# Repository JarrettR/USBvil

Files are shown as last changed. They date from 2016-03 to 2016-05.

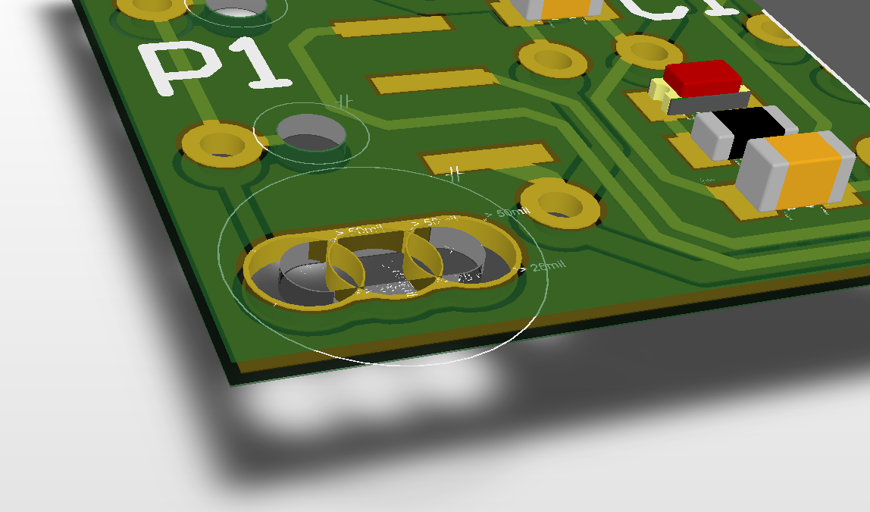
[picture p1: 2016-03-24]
Images/slots.PNG

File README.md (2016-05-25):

# USBvil
Don't plug in unknown flashdrives!

# What is this?

A demonstration of why flashdrives of unknown pedigree can be very dangerous.

See:
http://jrainimo.com/build/?p=601

The original goal was to have a very inexpensive (<$5) dev board that can be left in projects without feeling guilty. But it quickly turned into a USB experimentation project.

It fits into a standard USB flashdrive case, because that's super convenient, and it has one 8-pin port broken out for whatever this gets used for.

The "Blink.X" project in the firmware folder does exactly what it says on the tin. It's the obvious starter firmware to be forked for other stuff.

# Why is it dangerous?

The other two projects, HID and HID2 are slightly more complicated.
HID identifies itself as a USB keyboard and immediately starts typing a-z, and 0-9 upon being plugged in. This is barely changed from the Microchip example code, and doesn't include their USB libraries.

HID2 uses the same libraries, and identifies itself as a HID keyboard as well. It types `GUI-key->R, notepad.exe, hello world`. On a Windows machine, this opens Notepad and types "hello world".

Innocuous, but it's pretty obvious that this can be used in pretty scary ways.

That's pretty much as far as I intend to take this, I've lost interest. There might be methods of detecting what kind of computer the drive gets plugged into and tailoring the attack, too.

# How do I get started?

If you don't have the latest version of Microchip [MPLAB X](http://www.microchip.com/mplab/mplab-x-ide) and the [XC8 compiler](http://www.microchip.com/mplab/compilers), download them at the links. Everything is free.

To compile this, you'll need to go [here](http://www.microchip.com/mplab/microchip-libraries-for-applications) and download Microchip Libraries for Applications. It also includes some other very cool USB stuff.

After installation, go to whereever you installed it, and copy the `mla` folder into `Firmware` in this repo.

At the very least, you should have `USBvil\Firmware\mla\bsp` and `USBvil\Firmware\mla\framework` and all of the files inside.

After that, open up MPLAB, open project, and navigate to the `HID` folder - This is the more vanilla version, and better for starting something new. Compile it once to test, and then start modifying! `main.c` and `app_device_keyboard.c` are where the fun happens.

Alternatively, I have included the hex and elf firmware images if you just want to flash the board.

# How do I make one?

Just for kicks, I'm testing out Kitnic. Check it [here](https://kitnic.it/boards/github.com/JarrettR/USBvil/).

The service should make the board/BOM ordering process a little bit easier, we'll see how it goes. That's just a landing page to this repo, so all of the data is here, too.

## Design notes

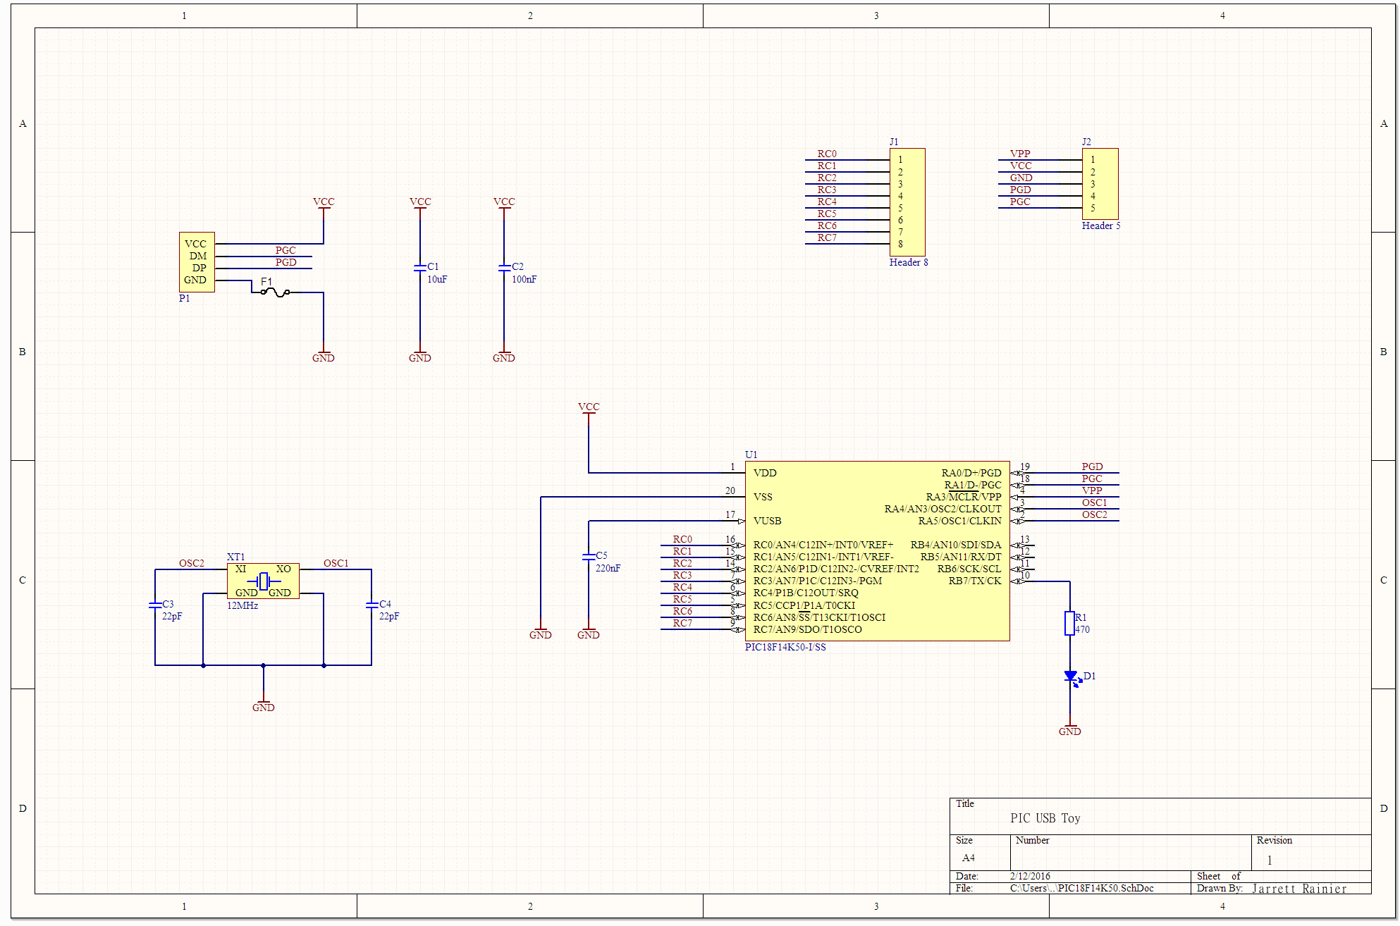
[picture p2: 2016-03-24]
Images/Schematic 1.PNG

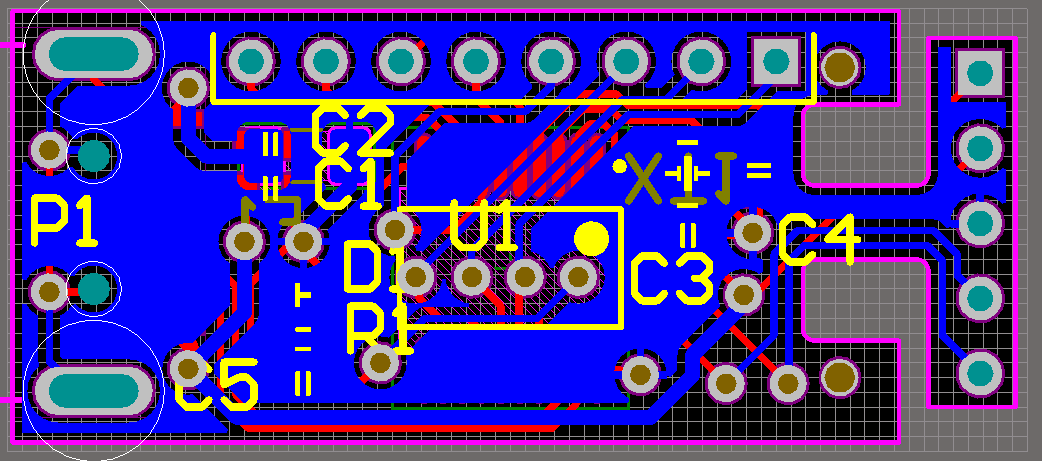
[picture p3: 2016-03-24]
Images/PCB Bottom.PNG

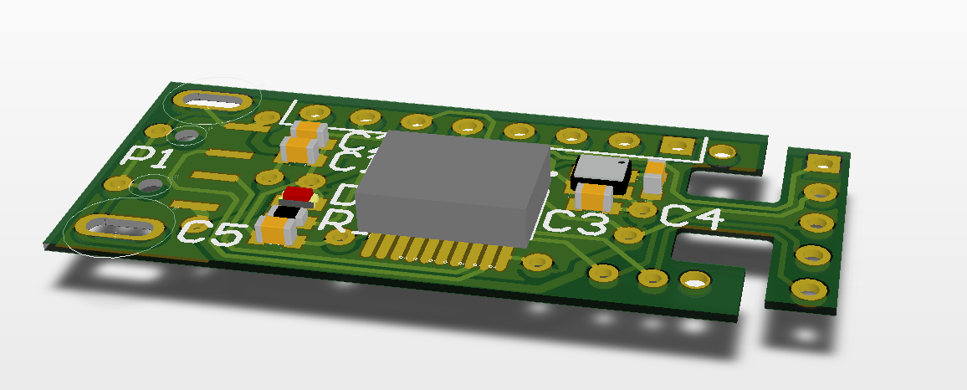
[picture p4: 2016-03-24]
Images/3D.PNG

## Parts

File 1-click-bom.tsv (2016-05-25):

References | Qty | Description | Manufacturer | MPN | Digikey | Mouser | RS | Newark | Farnell
C1 | 1 | MLCC - SMD/SMT 0603 1.0uF 6.3volts | Murata Electronics | GRM033R60J105MEA2D | 490-7229-1-ND | 81-GRM033R60J105ME2D
C2 | 1 | MLCC - SMD/SMT 0603 0.1uF 6.3volts | Murata Electronics | GRM033R60J104KE19D | 490-3167-1-ND | 81-GRM033R60J104KE19
C3, C4 | 2 | MLCC - SMD/SMT 0603 22pF 50volts | Murata Electronics | GRM0335C1H200GA01D | 490-6122-1-ND | 81-GRM0335C1H200GA1D
C5 | 1 | MLCC - SMD/SMT 0603 0.22uF 6.3volts | Murata Electronics | GRM033R60J224ME15D | 490-10407-1-ND | 81-GRM033R60J224ME5D
P1 | 1 | USB Connectors USB A PLUG SMT | Molex | 48037-2200 | WM3983CT-ND | 538-48037-2200
F1 | 1 | PTC RESTTBLE 0.75A 6V CHIP 1206 | Bel Fuse | 0ZCJ0075FF2E | 507-1804-1-ND | 530-0ZCJ0075FF2E
J1 | 1 | Female header, 8 position, unpopulated
J2 | 1 | Female header, 5 position, unpopulated
XT1 | 1 | 12MHz Crystal 20pF Surface Mount 4-SMD, No Lead (DFN, LCC) | CTS-Frequency Controls | 403C35E12M00000 | CTX1218CT-ND | 774-403C35E12M00000
U1 | 1 | IC MCU 8BIT 16KB FLASH 20SSOP | Microchip | PIC18F14K50-I/SS | PIC18F14K50-I/SS-ND | 579-PIC18F14K50-I/SS
R1 | 1 | RES SMD 470 OHM 5% 1/10W 0603 | Yageo | RC0603JR-07470RL | 311-470GRCT-ND | 603-RC0603JR-07470RL
D1 | 1 | LED BLUE CLEAR 0603 SMD | Wurth Electronics | 150060BS75000 | 732-4966-1-ND | 710-150060BS75000

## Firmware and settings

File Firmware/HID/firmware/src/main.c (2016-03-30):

/*******************************************************************************
  Main Demo File

  Company:
    Microchip Technology Inc.

  File Name:
    main.c

  Summary:
    Main demo file for keyboard project.  Entry point for compiler.

  Description:
    Main demo file for keyboard project.  Entry point for compiler.  Also
    calls the system initailization and handles system issues like calling the
    demo code appropriately and handing device level events from the USB stack.
*******************************************************************************/

// DOM-IGNORE-BEGIN
/*******************************************************************************
Copyright (c) 2013 released Microchip Technology Inc.  All rights reserved.

Microchip licenses to you the right to use, modify, copy and distribute
Software only when embedded on a Microchip microcontroller or digital signal
controller that is integrated into your product or third party product
(pursuant to the sublicense terms in the accompanying license agreement).

You should refer to the license agreement accompanying this Software for
additional information regarding your rights and obligations.

SOFTWARE AND DOCUMENTATION ARE PROVIDED "AS IS" WITHOUT WARRANTY OF ANY KIND,
EITHER EXPRESS OR IMPLIED, INCLUDING WITHOUT LIMITATION, ANY WARRANTY OF
MERCHANTABILITY, TITLE, NON-INFRINGEMENT AND FITNESS FOR A PARTICULAR PURPOSE.
IN NO EVENT SHALL MICROCHIP OR ITS LICENSORS BE LIABLE OR OBLIGATED UNDER
CONTRACT, NEGLIGENCE, STRICT LIABILITY, CONTRIBUTION, BREACH OF WARRANTY, OR
OTHER LEGAL EQUITABLE THEORY ANY DIRECT OR INDIRECT DAMAGES OR EXPENSES
INCLUDING BUT NOT LIMITED TO ANY INCIDENTAL, SPECIAL, INDIRECT, PUNITIVE OR
CONSEQUENTIAL DAMAGES, LOST PROFITS OR LOST DATA, COST OF PROCUREMENT OF
SUBSTITUTE GOODS, TECHNOLOGY, SERVICES, OR ANY CLAIMS BY THIRD PARTIES
(INCLUDING BUT NOT LIMITED TO ANY DEFENSE THEREOF), OR OTHER SIMILAR COSTS.
*******************************************************************************/
// DOM-IGNORE-END


// *****************************************************************************
// *****************************************************************************
// Section: Included Files
// *****************************************************************************
// *****************************************************************************
/* Standard C includes */
#include <stdint.h>

/* Microchip library includes */
#include "system.h"
#include "system_config.h"

#include "usb.h"
#include "usb_device_hid.h"

/* Demo project includes */
#include "app_led_usb_status.h"
#include "app_device_keyboard.h"



// *****************************************************************************
// *****************************************************************************
// Section: File Scope or Global Constants
// *****************************************************************************
// *****************************************************************************
volatile signed int SOFCounter = 0;


// *****************************************************************************
// *****************************************************************************
// Section: File Scope Data Types
// *****************************************************************************
// *****************************************************************************


// *****************************************************************************
// *****************************************************************************
// Section: Macros or Functions
// *****************************************************************************
// *****************************************************************************

int main(void)
{
    SYSTEM_Initialize( SYSTEM_STATE_USB_START );

    USBDeviceInit();
    USBDeviceAttach();
    
    unsigned int i = 0;
    unsigned int enable = 0;

    while(1)
    {
        SYSTEM_Tasks();

        #if defined(USB_POLLING)
        /* Check bus status and service USB interrupts.  Interrupt or polling
         * method.  If using polling, must call this function periodically.
         * This function will take care of processing and responding to SETUP
         * transactions (such as during the enumeration process when you first
         * plug in).  USB hosts require that USB devices should accept and
         * process SETUP packets in a timely fashion.  Therefore, when using
         * polling, this function should be called regularly (such as once every
         * 1.8ms or faster** [see inline code comments in usb_device.c for
         * explanation when "or faster" applies])  In most cases, the
         * USBDeviceTasks() function does not take very long to execute
         * (ex: <100 instruction cycles) before it returns. */
        USBDeviceTasks();
        #endif

        /* If the USB device isn't configured yet, we can't really do anything
         * else since we don't have a host to talk to.  So jump back to the
         * top of the while loop. */
        if( USBGetDeviceState() < CONFIGURED_STATE )
        {
            /* Jump back to the top of the while loop. */
            continue;
        }

        /* If we are currently suspended, then we need to see if we need to
         * issue a remote wakeup.  In either case, we shouldn't process any
         * keyboard commands since we aren't currently communicating to the host
         * thus just continue back to the start of the while loop. */
        if( USBIsDeviceSuspended()== true )
        {
            //Check if we should assert a remote wakeup request to the USB host,
            //when the user presses the pushbutton.
            if(BUTTON_IsPressed(BUTTON_USB_DEVICE_REMOTE_WAKEUP) == 0)
            {
                //Add code here to issue a resume signal.
            }

            /* Jump back to the top of the while loop. */
            continue;
        }

        /* Run the keyboard demo tasks. */
        //if(i > 0x00F0 && i < 0x00FF)
            APP_KeyboardTasks();
        
        i++;
    }//end while
}//end main


/*******************************************************************
 * Function:        bool USER_USB_CALLBACK_EVENT_HANDLER(
 *                        USB_EVENT event, void *pdata, uint16_t size)
 *
 * PreCondition:    None
 *
 * Input:           USB_EVENT event - the type of event
 *                  void *pdata - pointer to the event data
 *                  uint16_t size - size of the event data
 *
 * Output:          None
 *
 * Side Effects:    None
 *
 * Overview:        This function is called from the USB stack to
 *                  notify a user application that a USB event
 *                  occured.  This callback is in interrupt context
 *                  when the USB_INTERRUPT option is selected.
 *
 * Note:            None
 *******************************************************************/
bool USER_USB_CALLBACK_EVENT_HANDLER(USB_EVENT event, void *pdata, uint16_t size)
{
    switch((int)event)
    {
        case EVENT_TRANSFER:
            break;

        case EVENT_SOF:
            /* We are using the SOF as a timer to time the LED indicator.  Call
             * the LED update function here. */
            APP_LEDUpdateUSBStatus();
            if(SOFCounter < 32767)
            {
                SOFCounter++;
            }
            else
            {
                SOFCounter = 0;
            }
            break;

        case EVENT_SUSPEND:
            /* Update the LED status for the suspend event. */
            APP_LEDUpdateUSBStatus();

            //Call the hardware platform specific handler for suspend events for
            //possible further action (like optionally going reconfiguring the application
            //for lower power states and going to sleep during the suspend event).  This
            //would normally be done in USB compliant bus powered applications, although
            //no further processing is needed for purely self powered applications that
            //don't consume power from the host.
            SYSTEM_Initialize(SYSTEM_STATE_USB_SUSPEND);
            break;

        case EVENT_RESUME:
            /* Update the LED status for the resume event. */
            APP_LEDUpdateUSBStatus();

            //Call the hardware platform specific resume from suspend handler (ex: to
            //restore I/O pins to higher power states if they were changed during the 
            //preceding SYSTEM_Initialize(SYSTEM_STATE_USB_SUSPEND) call at the start
            //of the suspend condition.
            SYSTEM_Initialize(SYSTEM_STATE_USB_RESUME);
            break;

        case EVENT_CONFIGURED:
            /* When the device is configured, we can (re)initialize the keyboard
             * demo code. */
            APP_KeyboardInit();
            break;

        case EVENT_SET_DESCRIPTOR:
            break;

        case EVENT_EP0_REQUEST:
            /* We have received a non-standard USB request.  The HID driver
             * needs to check to see if the request was for it. */
            USBCheckHIDRequest();
            break;

        case EVENT_BUS_ERROR:
            break;

        case EVENT_TRANSFER_TERMINATED:
            break;

        default:
            break;
    }
    return true;
}

/*******************************************************************************
 End of File
*/

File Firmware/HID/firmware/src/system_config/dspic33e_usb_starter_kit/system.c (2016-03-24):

/********************************************************************
 Software License Agreement:

 The software supplied herewith by Microchip Technology Incorporated
 (the "Company") for its PIC(R) Microcontroller is intended and
 supplied to you, the Company's customer, for use solely and
 exclusively on Microchip PIC Microcontroller products. The
 software is owned by the Company and/or its supplier, and is
 protected under applicable copyright laws. All rights are reserved.
 Any use in violation of the foregoing restrictions may subject the
 user to criminal sanctions under applicable laws, as well as to
 civil liability for the breach of the terms and conditions of this
 license.

 THIS SOFTWARE IS PROVIDED IN AN "AS IS" CONDITION. NO WARRANTIES,
 WHETHER EXPRESS, IMPLIED OR STATUTORY, INCLUDING, BUT NOT LIMITED
 TO, IMPLIED WARRANTIES OF MERCHANTABILITY AND FITNESS FOR A
 PARTICULAR PURPOSE APPLY TO THIS SOFTWARE. THE COMPANY SHALL NOT,
 IN ANY CIRCUMSTANCES, BE LIABLE FOR SPECIAL, INCIDENTAL OR
 CONSEQUENTIAL DAMAGES, FOR ANY REASON WHATSOEVER.
 *******************************************************************/

#include <p33EP512MU810.h>
#include "system.h"
#include "system_config.h"
#include "usb.h"
#include "leds.h"
#include "buttons.h"
#include "adc.h"

/** CONFIGURATION Bits **********************************************/
// FGS
#pragma config GWRP = OFF               // General Segment Write-Protect bit (General Segment may be written)
#pragma config GSS = OFF                // General Segment Code-Protect bit (General Segment Code protect is disabled)
#pragma config GSSK = OFF               // General Segment Key bits (General Segment Write Protection and Code Protection is Disabled)

// FOSCSEL
#pragma config FNOSC = PRIPLL           // Initial Oscillator Source Selection Bits (Primary Oscillator (XT, HS, EC) with PLL)
#pragma config IESO = OFF               // Two-speed Oscillator Start-up Enable bit (Start up with user-selected oscillator source)

// FOSC
#pragma config POSCMD = HS              // Primary Oscillator Mode Select bits (HS Crystal Oscillator Mode)
#pragma config OSCIOFNC = ON            // OSC2 Pin Function bit (OSC2 is general purpose digital I/O pin)
#pragma config IOL1WAY = OFF            // Peripheral pin select configuration (Allow multiple reconfigurations)
#pragma config FCKSM = CSDCMD           // Clock Switching Mode bits (Both Clock switching and Fail-safe Clock Monitor are disabled)

// FWDT
#pragma config WDTPOST = PS32768        // Watchdog Timer Postscaler Bits (1:32,768)
#pragma config WDTPRE = PR128           // Watchdog Timer Prescaler bit (1:128)
#pragma config PLLKEN = ON              // PLL Lock Wait Enable bit (Clock switch to PLL source will wait until the PLL lock signal is valid.)
#pragma config WINDIS = OFF             // Watchdog Timer Window Enable bit (Watchdog Timer in Non-Window mode)
#pragma config FWDTEN = OFF             // Watchdog Timer Enable bit (Watchdog timer enabled/disabled by user software)

// FPOR
#pragma config FPWRT = PWR128           // Power-on Reset Timer Value Select bits (128ms)
#pragma config BOREN = OFF              // Brown-out Reset (BOR) Detection Enable bit (BOR is disabled)
#pragma config ALTI2C1 = OFF            // Alternate I2C pins for I2C1 (SDA1/SCK1 pins are selected as the I/O pins for I2C1)
#pragma config ALTI2C2 = OFF            // Alternate I2C pins for I2C2 (SDA2/SCK2 pins are selected as the I/O pins for I2C2)

// FICD
#pragma config ICS = PGD1               // ICD Communication Channel Select bits (Communicate on PGEC1 and PGED1)
#pragma config RSTPRI = PF              // Reset Target Vector Select bit (Device will obtain reset instruction from Primary flash)
#pragma config JTAGEN = OFF             // JTAG Enable bit (JTAG is disabled)

// FAS
#pragma config AWRP = OFF               // Auxiliary Segment Write-protect bit (Auxiliary program memory is not write-protected)
#pragma config APL = OFF                // Auxiliary Segment Code-protect bit (Aux Flash Code protect is disabled)
#pragma config APLK = OFF               // Auxiliary Segment Key bits (Aux Flash Write Protection and Code Protection is Disabled)

/*********************************************************************
* Function: void SYSTEM_Initialize( SYSTEM_STATE state )
*
* Overview: Initializes the system.
*
* PreCondition: None
*
* Input:  SYSTEM_STATE - the state to initialize the system into
*
* Output: None
*
********************************************************************/
void SYSTEM_Initialize( SYSTEM_STATE state )
{
    switch(state)
    {
        case SYSTEM_STATE_USB_START:
            ANSELA = 0x0000;
            ANSELB = 0x0000;
            ANSELC = 0x0000;
            ANSELD = 0x0000;
            ANSELE = 0x0000;
            ANSELG = 0x0000;

            // Configure the device PLL to obtain 60 MIPS operation. The crystal
            // frequency is 8MHz. Divide 8MHz by 2, multiply by 60 and divide by
            // 2. This results in Fosc of 120MHz. The CPU clock frequency is
            // Fcy = Fosc/2 = 60MHz. Wait for the Primary PLL to lock and then
            // configure the auxilliary PLL to provide 48MHz needed for USB
            // Operation.

            PLLFBD = 58;                        /* M  = 60  */
            CLKDIVbits.PLLPOST = 0;             /* N1 = 2   */
            CLKDIVbits.PLLPRE = 0;              /* N2 = 2   */
            OSCTUN = 0;

            /*	Initiate Clock Switch to Primary
             *	Oscillator with PLL (NOSC= 0x3)*/
            __builtin_write_OSCCONH(0x03);
            __builtin_write_OSCCONL(0x01);

            while (OSCCONbits.COSC != 0x3);

            // Configuring the auxiliary PLL, since the primary
            // oscillator provides the source clock to the auxiliary
            // PLL, the auxiliary oscillator is disabled. Note that
            // the AUX PLL is enabled. The input 8MHz clock is divided
            // by 2, multiplied by 24 and then divided by 2. Wait till
            // the AUX PLL locks.

            ACLKCON3 = 0x24C1;
            ACLKDIV3 = 0x7;

            ACLKCON3bits.ENAPLL = 1;
            while(ACLKCON3bits.APLLCK != 1);

            LED_Enable(LED_USB_DEVICE_STATE);
            LED_Enable(LED_USB_DEVICE_HID_KEYBOARD_CAPS_LOCK);
            
            BUTTON_Enable(BUTTON_USB_DEVICE_HID_KEYBOARD_KEY);
            break;

        case SYSTEM_STATE_USB_SUSPEND:
            //If developing a bus powered USB device that needs to be USB compliant,
            //insert code here to reduce the I/O pin and microcontroller power consumption,
            //so that the total current is <2.5mA from the USB host's VBUS supply.
            //If developing a self powered application (or a bus powered device where
            //official USB compliance isn't critical), nothing strictly needs
            //to be done during USB suspend.

            USBSleepOnSuspend();
            break;
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

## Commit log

2016-03-22 Hardware files
    [PIC18F14K50 Male.PcbDoc, PIC18F14K50.PrjPCB, PIC18F14K50.SchDoc]
2016-03-23 Fixed file structure, added outputs
    [PIC18F14K50 Male.PcbDoc, PIC18F14K50.PrjPCB, PIC18F14K50.SchDoc]
2016-05-25 Added support for kitnic
    [1-click-BOM.tsv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]
2016-05-25 Update to new kitnic conventions
    [1-click-bom.tsv]
